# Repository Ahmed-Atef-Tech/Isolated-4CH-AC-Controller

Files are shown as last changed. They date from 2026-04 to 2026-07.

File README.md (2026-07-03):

# Isolated-4CH-AC-Controller

**ISO-AC4-FB:** A 4-Channel isolated AC controller (220V/8A) engineered in KiCad. Designed for high reliability with Solid State Relays (SSRs), active AC feedback, 1oz copper traces, and strict safety isolation routing.





ISO-AC4-FB Controller_page-0001

---

##  Uncompromising Safety Features

Designing a mixed-signal board that handles 220V AC alongside 5V DC logic demands strict adherence to safety standards. This board incorporates multiple layers of electrical and physical protection to ensure user safety and device longevity:

* **Transient Surge Protection (MOV):** A 10D431K Varistor is placed in parallel with the main AC input to absorb damaging voltage spikes and transients from the mains supply, protecting the downstream SSRs and loads.
* **Individual Channel Overcurrent Protection:** Instead of relying on a single main fuse, each of the 4 output channels is individually protected by a dedicated fuse. This ensures that a short circuit or overload on one specific load will safely blow its respective fuse without shutting down the entire system or damaging the SSR.
* **Physical Isolation Slots (Creepage Enhancement):** To completely eliminate the risk of high-voltage arcing across the PCB surface, 1.0mm milled isolation slots were routed between the high-voltage (AC) and low-voltage (DC) zones. This physically converts the creepage distance into clearance, vastly exceeding standard safety requirements.
* **Silkscreen Safety Demarcation:** For safe handling and maintenance, the AC high-voltage region is explicitly demarcated on the silkscreen layer with clear boundary lines and "DANGER / HIGH VOLTAGE" warnings. This visual barrier prevents accidental contact by technicians during assembly or testing.

ISO-AC4-FB Controller
ISO-AC4-FB Controller1

---

##  Component Highlight: Why Omron G3MB SSRs?

For the switching mechanism, traditional Electro-Mechanical Relays (EMRs) and discrete TRIAC circuits were intentionally avoided in favor of the **Omron G3MB Series Solid State Relays (SSRs)**. This selection provides several massive engineering advantages:

* **Integrated Zero-Cross Circuitry:** By utilizing the zero-cross models (e.g., G3MB-202P / PEG), the SSR only switches the load when the AC sine wave crosses 0V. This eliminates destructive arcing, prevents massive inrush currents, and completely removes the need to design a complex external zero-crossing detection circuit.
* **Built-in RC Snubber:** The relay features an internal snubber circuit that absorbs sudden voltage spikes (dv/dt) typically generated by inductive loads. This provides robust protection without requiring external capacitors and resistors.
* **Ultra-Compact Footprint (SIP-4):** The vertical Single In-line Package takes up a fraction of the PCB space compared to bulky mechanical relays, which was crucial for fitting 4 fully isolated AC channels on a single compact board.
* **Silent Operation & Infinite Lifespan:** As a semiconductor device with no moving parts, the SSR operates in absolute silence (a mandatory requirement for smart home automation) and is immune to mechanical wear, contact degradation, or welding, guaranteeing a virtually infinite lifespan.
* **Low Drive Current:** The internal LED requires extremely low trigger current (~10-20mA at 5V). This allows the SSRs to be driven directly by standard logic-level signals, completely eliminating the need for external BJT driving transistors and flyback diodes.



---

##  How the Active AC Feedback Works

Unlike standard relay boards that blindly send a control signal without knowing the actual state of the load, this board actively monitors the AC output to verify that power is successfully reaching the terminal. 

The feedback loop operates through a secure, 4-step hardware process:

1. **Voltage Sampling:** When the SSR turns on and 220V AC is present at the output terminal, a minuscule sample current (~2mA) is tapped through high-value current-limiting resistors (e.g., 47kΩ).
2. **Optical Isolation:** This sample current drives the internal bidirectional LEDs of an **LTV-814 AC Optocoupler**. This guarantees absolute galvanic isolation—transferring the status signal via light while keeping the 220V mains completely separated from the 5V logic side.
3. **Signal Conditioning:** Because the 50Hz AC mains crosses zero 100 times per second, the optocoupler's transistor output inherently pulses. To prevent erratic MCU readings, a **10uF smoothing capacitor** paired with a 10kΩ pull-down resistor acts as a low-pass filter, converting the pulsed output into a clean, stable DC logic level.
4. **MCU Logic Verification:** 
   * **State HIGH (5V):** The MCU reads a solid HIGH, confirming the load is actively powered.
   * **State LOW (0V):** The MCU reads LOW, instantly indicating that the SSR is off, the channel's fuse has blown, or there is a total mains power failure.

---

##  Known Limitations and Proposed Revisions (Rev 2.0)

**1. AC Routing Topology & Isolation Constraints**
* **Current Implementation:** Due to strict board size constraints in this initial prototype, the 220V `AC_N` line (used strictly for low-current voltage sensing/feedback) and the 5V `VCC` logic line were routed using a Daisy-Chain topology. Trace widths were set to 0.5mm, which is electrically sufficient for the minimal control current (~10mA).
* **Engineering Assessment:** While the current capacity is well within safe margins for a 1oz copper board, the daisy-chain approach in the high-voltage section makes it difficult to maintain optimal IPC-2221 clearance distances. Relying solely on soldermask for high-voltage separation is not ideal for long-term industrial reliability.
* **Action Plan for Production (Rev 2.0):** The next revision will transition the high-voltage routing to a **Star Topology** directly from the input terminal. Furthermore, isolation milling slots will be implemented between the interconnected AC nodes to strictly enforce standard creepage distances.

**2. Wireless Connectivity & IoT Integration**
* **Action Plan for Rev 2.0:** The current prototype relies on an external microcontroller connected via pin headers. In the next revision, the component placement and routing will be heavily optimized to include a dedicated socket for an **ESP-01 module** (or a fully integrated **ESP8266/ESP32** circuit). This will allow the PCB to act as a standalone, plug-and-play IoT shield, enabling seamless Wi-Fi control and smart home integration right out of the box without any external wiring.

**3. Mechanical Design & Productization**
* **Action Plan for Rev 2.0:** To bridge the gap between a bare PCB and a consumer-ready device, a custom **3D-printable enclosure** will be designed. This will provide a professional aesthetic, ensure secure mounting, and most importantly, guarantee physical isolation and safety from high-voltage AC contacts for the end-user.

**4. Schematic Refactoring & Annotation Optimization**
* **Action Plan for Rev 2.0:** The schematic diagram will be completely refactored to enhance readability and logical flow. Component designators will be systematically re-annotated and grouped by functional blocks (e.g., sequentially per channel). This structured approach will significantly simplify troubleshooting, improve the BOM organization, and streamline the overall PCB assembly process.

---

##  BOM Corrections (Important)

Please note the following two assembly corrections regarding the current `.kicad_sch` labels:

1. **Fuses (F1-F4):** The schematic shows **2.5A**, but the SSR max limit is 2A. You **MUST use 1.5A or 2A Fast-Acting fuses** to safely protect the relays from overload.
2. **SSR Model:** The schematic lists `G3MB-202PL` (Random-ON). To leverage the Zero-Cross switching and EMI reduction features, you must install the **`G3MB-202P`** or **`G3MB-202PEG`** (with built-in snubber) variants instead.

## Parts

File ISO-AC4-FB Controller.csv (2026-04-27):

Id | Designator | Footprint | Quantity | Designation | Supplier and ref
1 | K2,K1,K4,K3 | RELAY_G3MB-202P_DC12 | 4 | G3MB-202PL
2 | R2,R4,R15,R16,R12,R1,R5,R11 | R_2512_6332Metric | 8 | 47kΩ
3 | R17,R8,R14,R7 | R_1206_3216Metric | 4 | 10kΩ
4 | R13,R18,R3,R6 | R_1206_3216Metric | 4 | 1kΩ
5 | F1,F2,F4,F3 | FUSE_36911000000 | 4 | Fuse 2.5A
6 | D2,D5,D6,D1 | LED_1206_3216Metric | 4 | FB_LED1
7 | J1 | PinHeader_1x10_P2.54mm_Vertical | 1 | Microcontroller Connectors
8 | D3 | LED_1206_3216Metric | 1 | PWR_LED
9 | U1,U4,U3,U2 | DIP-4_W7.62mm | 4 | LTV-814
10 | R9,R10 | R_1206_3216Metric | 2 | 100kΩ
11 | C2,C4,C3,C1 | C_1206_3216Metric | 4 | 10uF
12 | D4 | D_SMA | 1 | 1N4007
13 | J2 | TerminalBlock_Phoenix_MKDS-3-6-5.08_1x06_P5.08mm_Horizontal | 1 | Conn_01x06
14 | RV1 | RV_Disc_D12mm_W4mm_P7.5mm | 1 | Varistor_10D431K

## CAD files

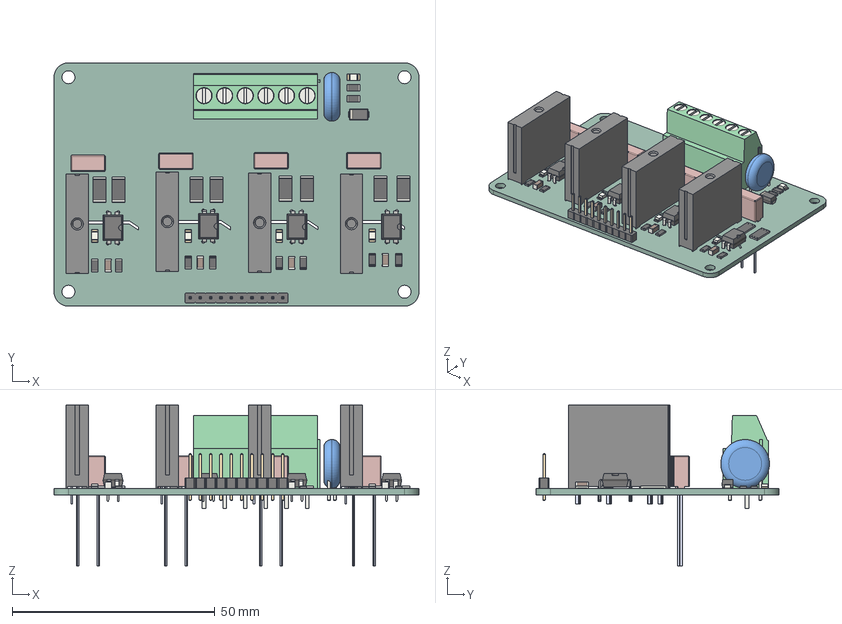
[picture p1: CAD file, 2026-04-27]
ISO-AC4-FB Controller.step
89.9 x 59.9 x 39.6 mm
G3MB-202PL x 4
R_2512_6332Metric x 8
R_1206_3216Metric x 10
LED_1206_3216Metric x 5
PinHeader_1x10_P2.54mm_Vertical
DIP-4_W7.62mm x 4
C_1206_3216Metric x 4
D_SMA
TerminalBlock_Phoenix_MKDS-3-6-5.08_1x06_P5.08mm_Horizontal
RV_Disc_D12mm_W4mm_P7.5mm
ISO-AC4-FB Controller_PCB

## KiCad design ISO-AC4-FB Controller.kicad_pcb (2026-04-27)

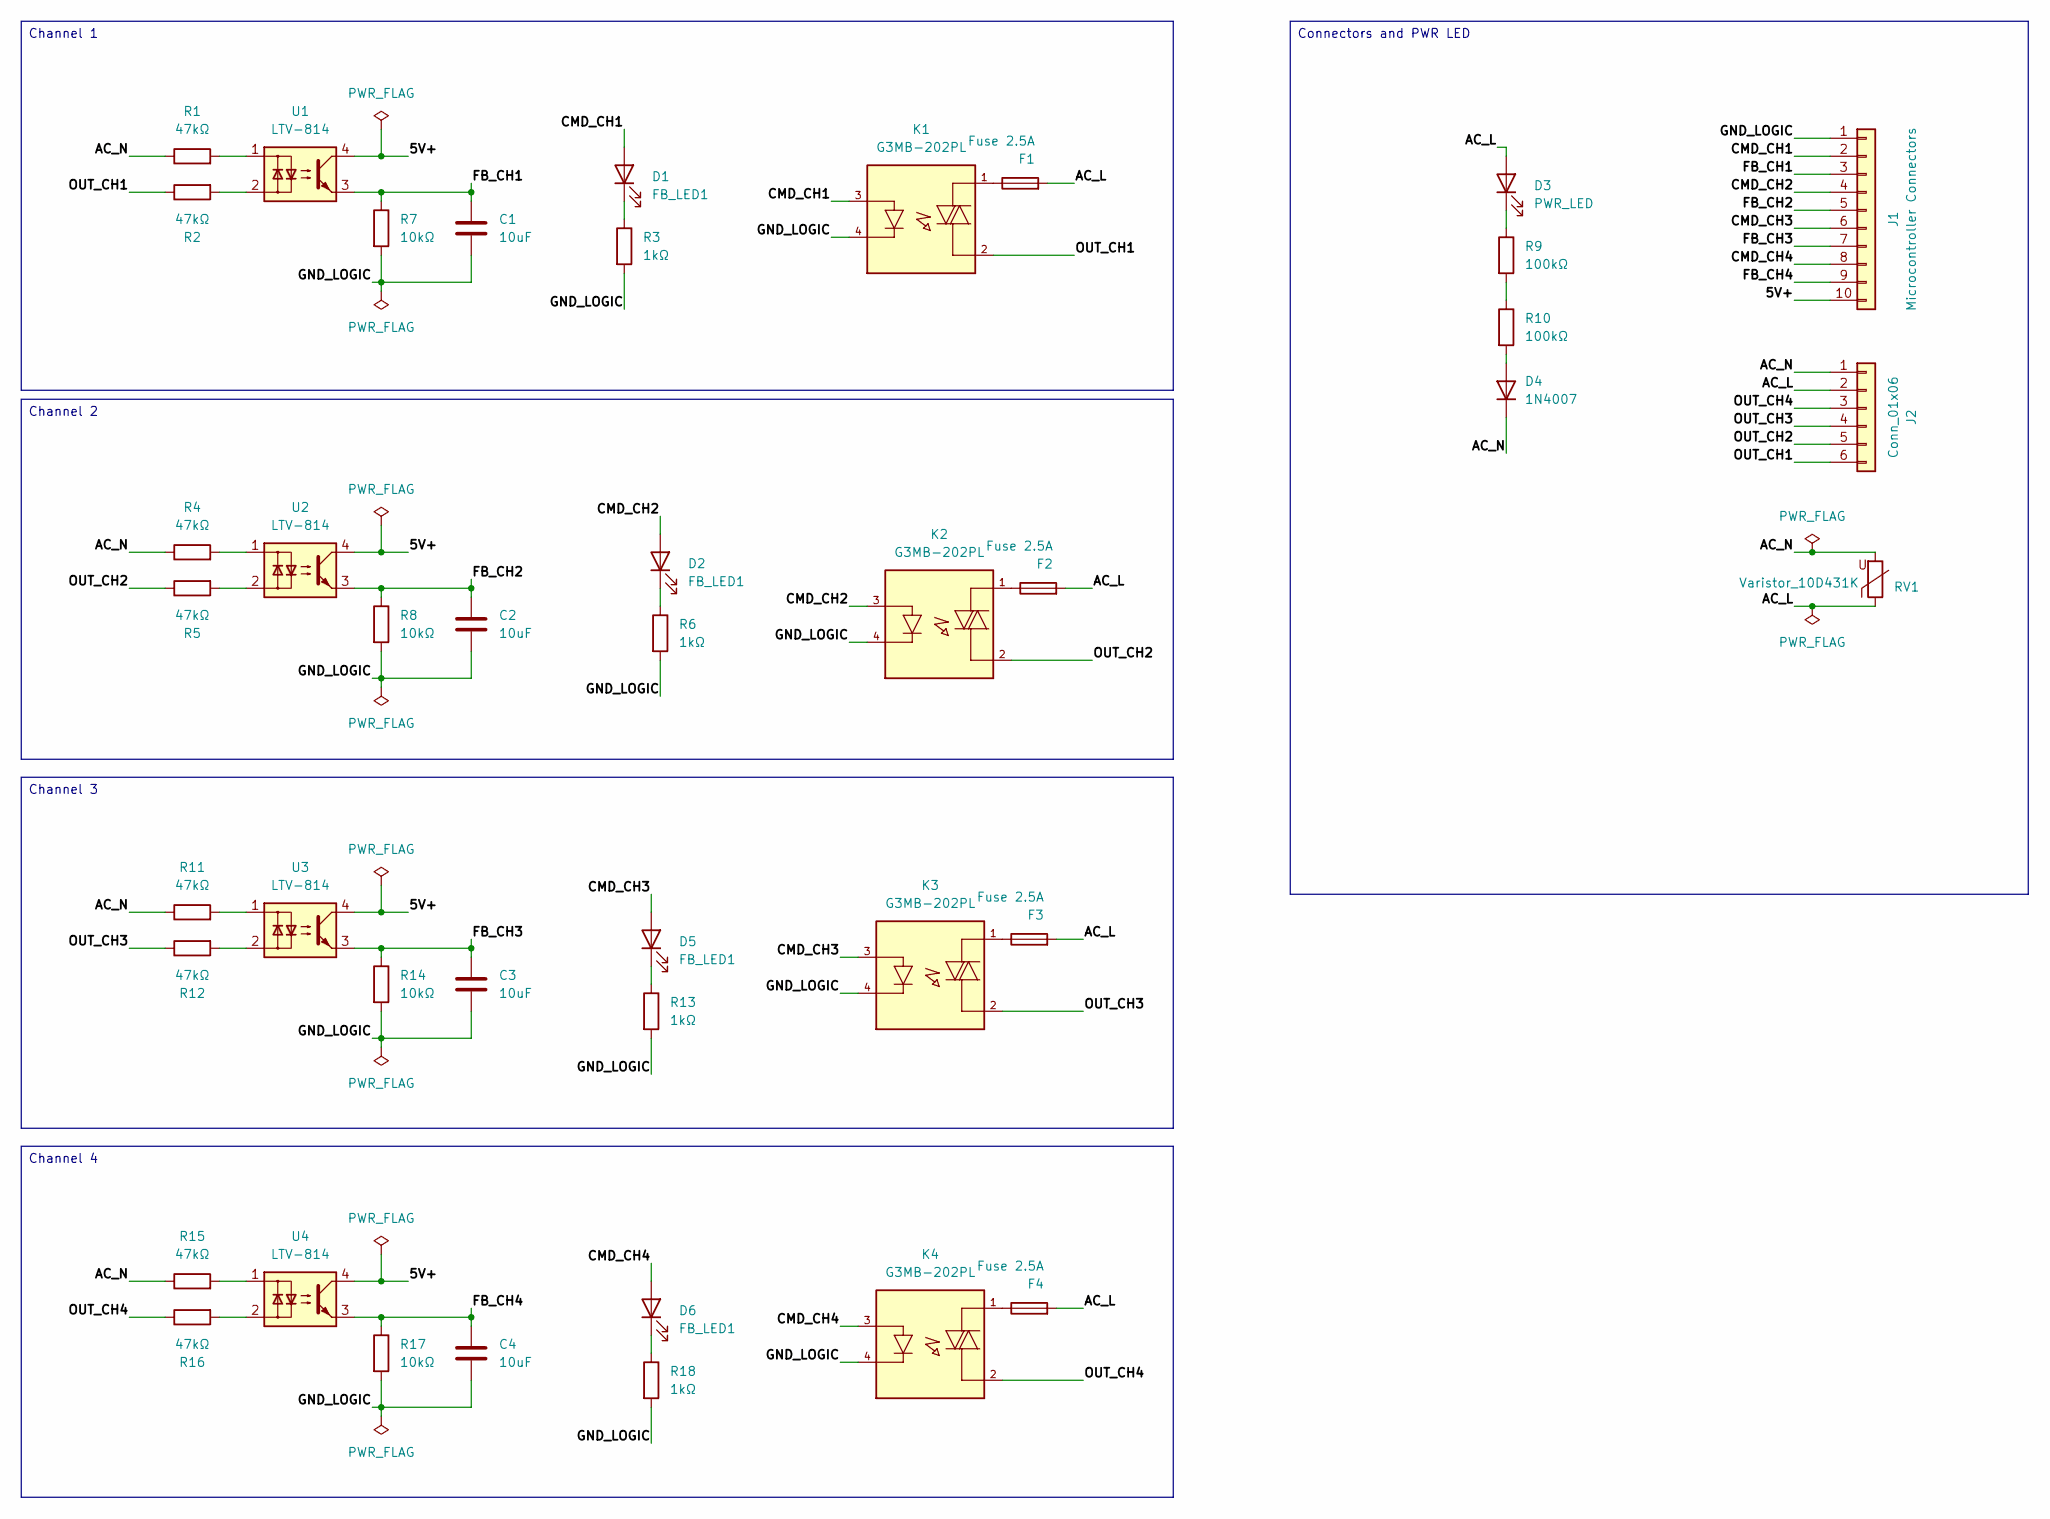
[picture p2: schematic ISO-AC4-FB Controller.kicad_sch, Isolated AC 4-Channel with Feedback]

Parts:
C1, C2, C3, C4: 10uF; C_1206_3216Metric
D1, D2, D5, D6: FB_LED1; LED_1206_3216Metric
D3: PWR_LED; LED_1206_3216Metric
D4: 1N4007; D_SMA
F1, F2, F3, F4: Fuse 2.5A; FUSE_36911000000
J1: Microcontroller Connectors; PinHeader_1x10_P2.54mm_Vertical
J2: Conn_01x06; TerminalBlock_Phoenix_MKDS-3-6-5.08_1x06_P5.08mm_Horizontal
K1, K2, K3, K4: G3MB-202PL; RELAY_G3MB-202P_DC12; PARTREV 06/09
R1, R2, R4, R5, R11, R12, R15, R16: 47kΩ; R_2512_6332Metric
R3, R6, R13, R18: 1kΩ; R_1206_3216Metric
R7, R8, R14, R17: 10kΩ; R_1206_3216Metric
R9, R10: 100kΩ; R_1206_3216Metric
RV1: Varistor_10D431K; RV_Disc_D12mm_W4mm_P7.5mm
U1, U2, U3, U4: LTV-814; DIP-4_W7.62mm

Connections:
/5V+: J1.10, U1.4, U2.4, U3.4, U4.4
/AC_L: D3.2 (A), F1.2, F2.2, F3.2, F4.2, J2.2, RV1.1
/AC_N: D4.1 (K), J2.1, R1.1, R4.1, R11.1, R15.1, RV1.2
/CMD_CH1: D1.2 (A), J1.2, K1.3
/CMD_CH2: D2.2 (A), J1.4, K2.3
/CMD_CH3: D5.2 (A), J1.6, K3.3
/CMD_CH4: D6.2 (A), J1.8, K4.3
/FB_CH1: C1.1, J1.3, R7.1, U1.3
/FB_CH2: C2.1, J1.5, R8.1, U2.3
/FB_CH3: C3.1, J1.7, R14.1, U3.3
/FB_CH4: C4.1, J1.9, R17.1, U4.3
/GND_LOGIC: C1.2, C2.2, C3.2, C4.2, J1.1, K1.4, K2.4, K3.4, K4.4, R3.2, R6.2, R7.2, R8.2, R13.2, R14.2, R17.2, R18.2
/OUT_CH1: J2.6, K1.2, R2.1
/OUT_CH2: J2.5, K2.2, R5.1
/OUT_CH3: J2.4, K3.2, R12.1
/OUT_CH4: J2.3, K4.2, R16.1
unnamed: D1.1 (K), R3.1
unnamed: D2.1 (K), R6.1
unnamed: D3.1 (K), R9.1
unnamed: D4.2 (A), R10.2
unnamed: D5.1 (K), R13.1
unnamed: D6.1 (K), R18.1
unnamed: F1.1, K1.1
unnamed: F2.1, K2.1
unnamed: F3.1, K3.1
unnamed: F4.1, K4.1
unnamed: R1.2, U1.1
unnamed: R2.2, U1.2
unnamed: R4.2, U2.1
unnamed: R5.2, U2.2
unnamed: R9.2, R10.1
unnamed: R11.2, U3.1
unnamed: R12.2, U3.2
unnamed: R15.2, U4.1
unnamed: R16.2, U4.2

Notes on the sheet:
Channel 4
Channel 3
Connectors and PWR LED
Channel 2
Channel 1

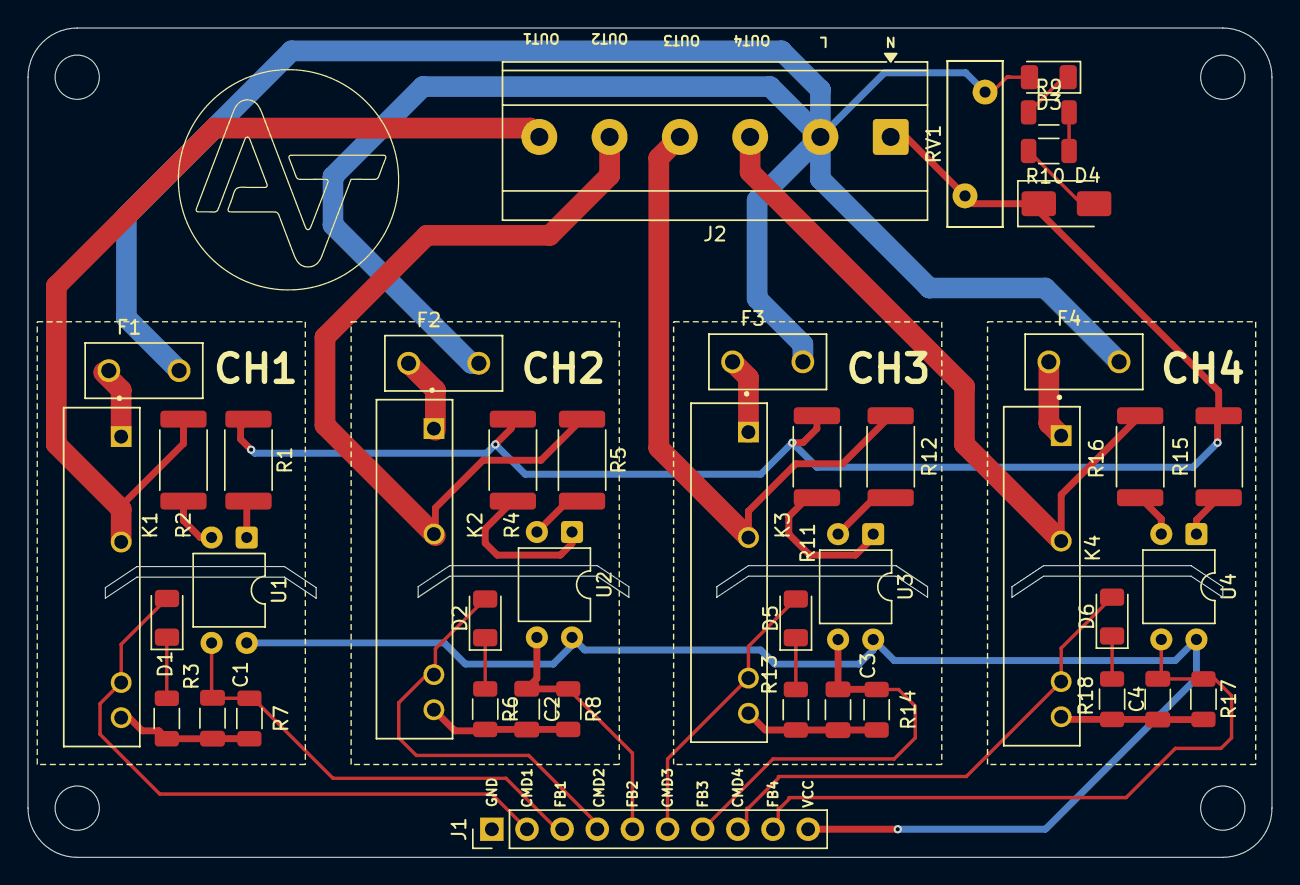
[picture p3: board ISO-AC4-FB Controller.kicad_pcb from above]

Board: 2 copper layers, 89.9 x 59.9 mm, 43 parts (0 on the bottom side), 35 nets.
